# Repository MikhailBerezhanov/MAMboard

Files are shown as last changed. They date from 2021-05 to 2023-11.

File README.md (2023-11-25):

# Mobile audio module (MAM) 
## pcb

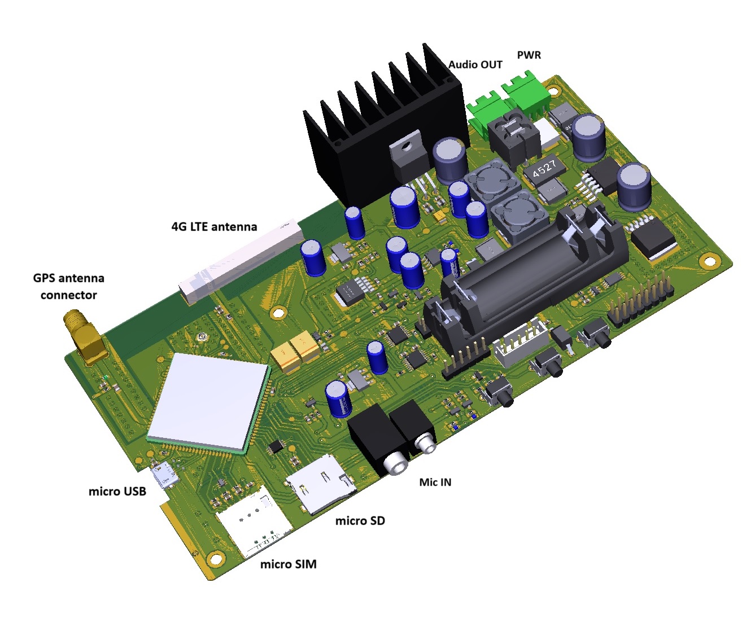
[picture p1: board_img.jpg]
board image


This project includes board scheme and manufacturing details. Current revision is `1.1`.
Board main features:
* Input power range 14V..28V
* Reserve 4.2V Accumulator power source for MPU
* Internet connection using onbard 4G LTE (SIM card needed)
* GPS connection (3V external antenna needed)
* AUDIO In (microphone input can be routed to amplified audio out)
* AUDIO Out Amplified (ready for external speaker use)
* External Memory storage (uSD card)
* ADB console (microUSB)
* Open-Linux programmable board

### Dependencies
PCB development is performed using `Altium Designer 19` or versions higher.
Components library is linked as separate submodule:

```bash
git submodule init
git submodule update
cd pcb/libs
git checkout master
```

### Manufacturing and assembly
Current project provides all necessary files for _pcb order_:

* Bill of materials (BOM)
* Gerber files
* Assembly drawings

Files mentioned above are located in:
`./pcb/vX.X/Project Outputs for Autoinformer_vX.X/`

where `X.X` is version of the board. The lastest version for now is `1.1`.

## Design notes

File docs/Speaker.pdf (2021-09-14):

### 15 ГДШ-3

Номинальное электрическое сопротивление | 4, 8 Ом
Предельная шумовая мощность | 15 Вт
Предельная кратковременная мощность | 50 Вт
Эффективный рабочий диапазон частот | 125:10000 Гц
Уровень характеристической чувствительности 89+/-4 дБ
Масса | 0.5 кг.
Габаритные размеры | 128x128x55 мм
Установочные размеры | 100x100 мм

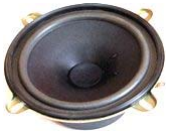
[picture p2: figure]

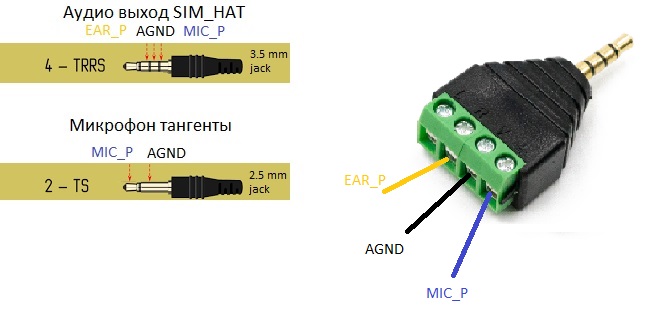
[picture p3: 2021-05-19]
docs/SIM_HAT_JACKS_PINOUT.jpg

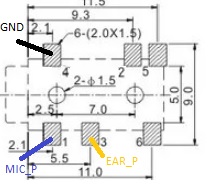
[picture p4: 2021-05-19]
docs/SIM_HAT_AUDIO_PINOUT.jpg

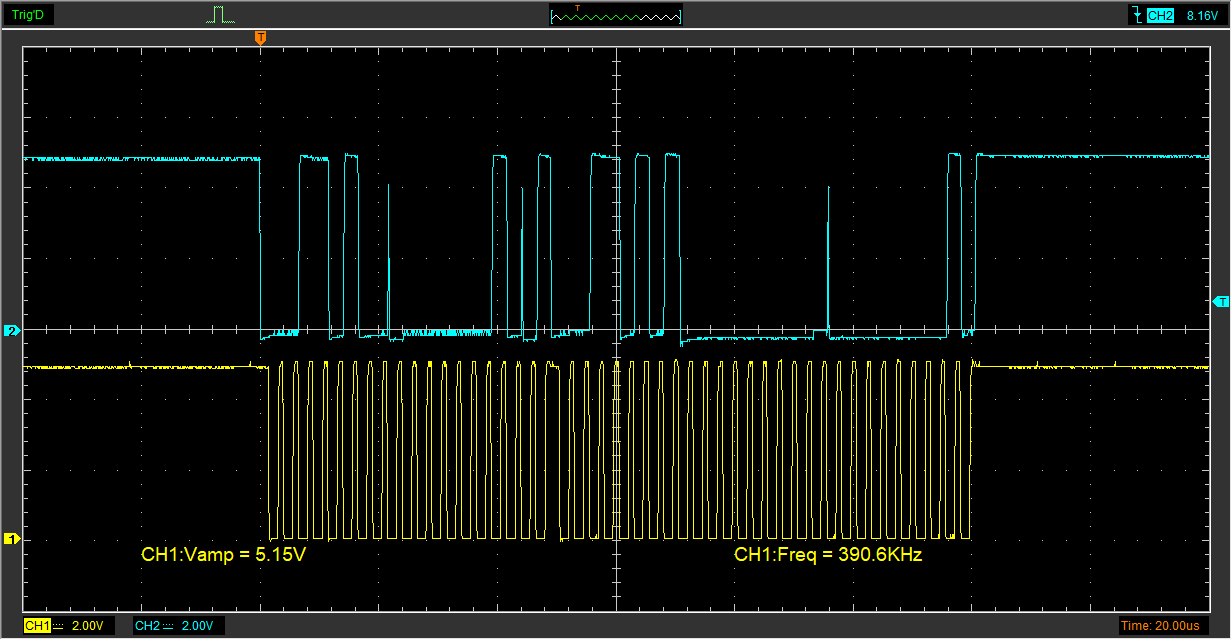
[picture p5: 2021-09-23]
docs/oscilloscopes/LCD/Real_BSS138_5V_lvl_shifter.jpg

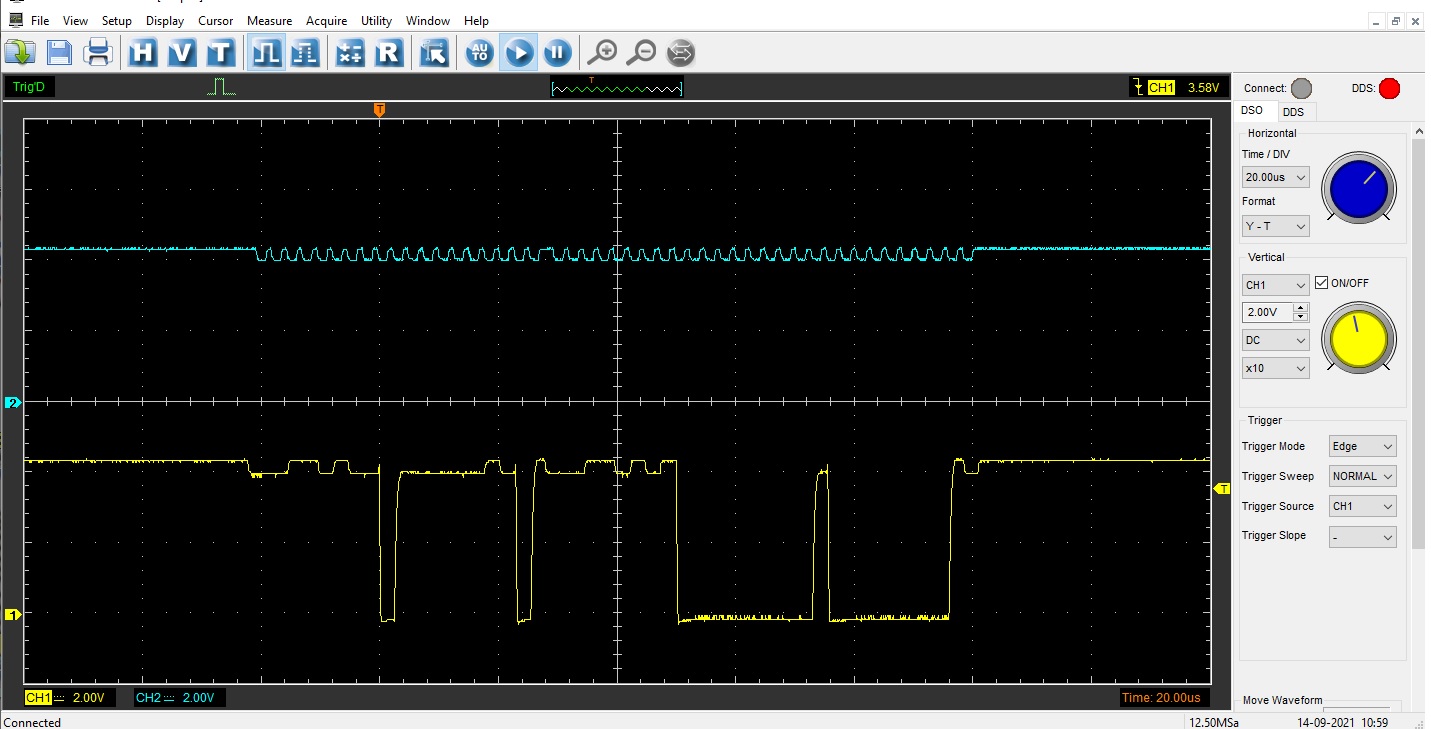
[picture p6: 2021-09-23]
docs/oscilloscopes/LCD/BSS138_lvl_shifter_i2c_400khz.jpg

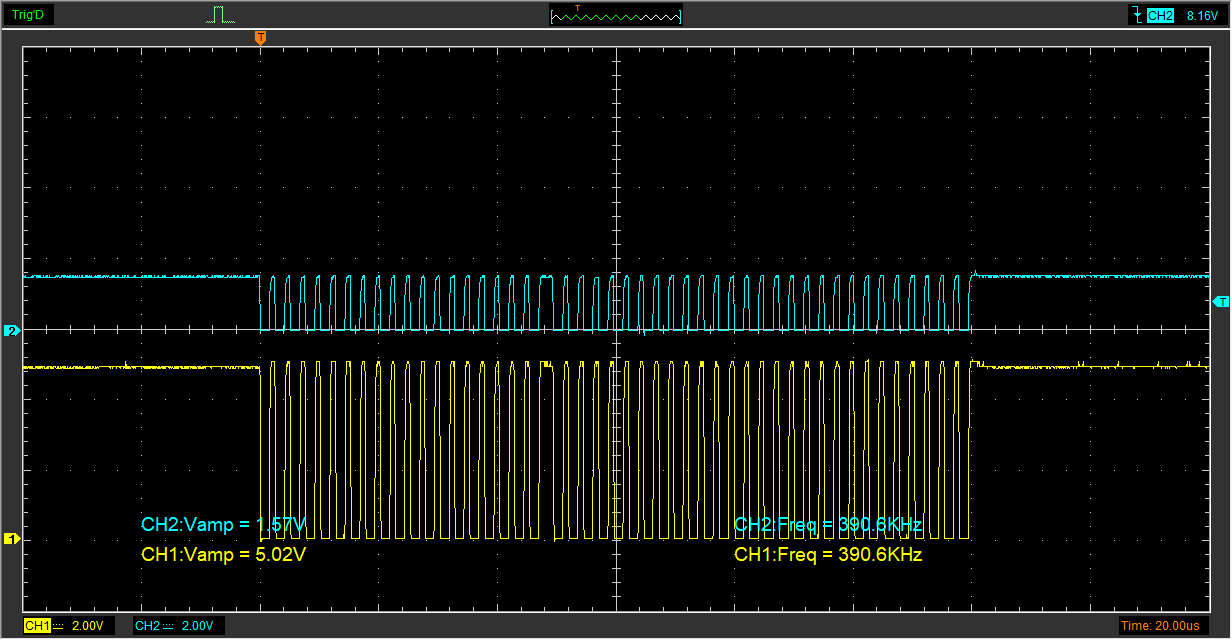
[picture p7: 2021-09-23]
docs/oscilloscopes/LCD/Real_BSS138_SCL.jpg

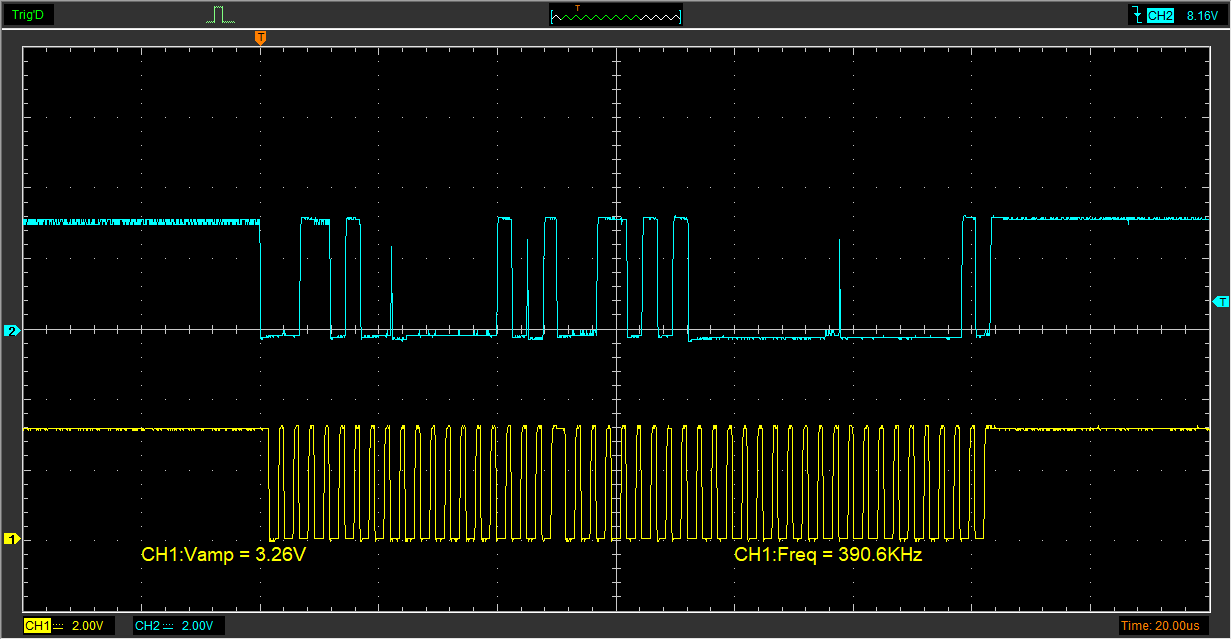
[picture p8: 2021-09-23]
docs/oscilloscopes/LCD/Real_bss318_lvll_shifter.jpg

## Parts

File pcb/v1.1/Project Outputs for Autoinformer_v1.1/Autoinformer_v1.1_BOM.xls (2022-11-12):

Designator | Comment | Description | Quantity | Link1URL | Link2URL | Link3URL | Link4URL | Link5URL | Link6URL | Link7URL
ANT1 | 146200-00011 | LTE Cellular Ceramic Antenna 698MHz-2.7GHz , SMT | 1 | https://www.elitan.ru/price/item17428368
C1, C11, C12, C13, C24, C28 | 4.7uF | GRM188R60J475KE19D | 6 | https://www.chipdip.ru/product/grm188r60j475ke19d | https://www.electronshik.ru/item/MUR/GRM188R60J475KE19D
C2, C3, C8, C14, C15, C16, C32, C34, C35, C40, C45, C46, C47, C48, C49, C52, C53, C54, C59, C67, C68, C71, C76, C77, C79, C82 | 0.1uF | GRM188R71H104KA93D | 26 | https://www.chipdip.ru/product0/226236018 | https://www.electronshik.ru/item/MUR/GRM188R71H104KA93D
C4, C6, C17, C18, C29 | 10pF | GRM1885C1H100J | 5 | https://www.chipdip.ru/product/grm1885c1h100j | https://www.electronshik.ru/item/MUR/GRM1885C1H100JA01D
C5, C7, C9, C50, C51 | 22pF | GRM1885C1H220JA01D | 5 | https://www.chipdip.ru/product/grm1885c1h220j | https://www.electronshik.ru/item/MUR/GRM1885C1H220JA01D
C10 | 10nF | GRM188R71H103K | 1 | https://www.chipdip.ru/product0/9000143994 | https://www.electronshik.ru/item/MUR/GRM188R71H103KA01D
C19, C20, C44 | 33pF | GRM1885C1H330J | 3 | https://www.chipdip.ru/product0/565764982 | https://www.electronshik.ru/item/MUR/GRM1885C1H330JA01D
C21 | 100pF | GRM1885C1H101J | 1 | https://www.chipdip.ru/product0/305749128 | https://www.electronshik.ru/item/MUR/GRM1885C1H101JA01D
C22, C23, C25, C63 | 1uF | GRM188R71E105KA12D | 4 | https://www.chipdip.ru/product/grm188r71e105ka12d | https://www.electronshik.ru/item/MUR/GRM188R71E105KA12D
C26, C27 | 470uF 6.3V | 293D477X06R3E2TE3 Конденсатор танталовый SMD тип Е | 2 | https://www.chipdip.ru/product0/145634327?from=suggest_product
C30 | 1uF | GRM31MR71E105KA01L | 1 | https://www.chipdip.ru/product/grm31mr71e105k | https://www.electronshik.ru/item/MUR/GRM31MR71E105KA01L
C31 | 10uF 10V | Конденсатор танталовый SMD 10uF 10V тип B | 1 | https://www.chipdip.ru/product0/146061461?from=suggest_product
C33, C80, C81 | 0.1uF | CL05B104KO5NNNC (CC0402KRX7R7BB104) | 3 | https://www.chipdip.ru/product1/8001849671?from=suggest_product | https://www.electronshik.ru/item/SAMSUNG/CL05B104KO5NNNC
C36 | 0.039uF | CC0603KRX7R9BB393 | 1 | https://www.chipdip.ru/product0/8160066189?from=suggest_product | https://www.elitan.ru/price/item8778633 | https://www.electronshik.ru/item/YAG/CC0603KRX7R9BB393
C37 | K50-35 470uF 16V | Конденсатор электролитический алюминиевый 470мкФ, 16В, 8х12мм Р:3.5мм | 1 | https://www.chipdip.ru/product0/9000565914
C38, C39 | K50-35 1000uF 25V | Конденсатор электролитический алюминиевый 1000мкФ, 25В, 10x21мм | 2 | https://www.chipdip.ru/product0/9000565765?from=suggest_product
C41 | 22pF | GRM21A5C2E220J (CC0805JRNPO9BN220) | 1 | https://www.chipdip.ru/product0/29844 | https://www.electronshik.ru/item/MUR/GRM21A5C2E220JW01D
C42, C43 | NС | 0603 SMD Capacitor | 2
C55 | 100pF 2kV | C1206C101KGRACAUTO (CC1206JKNPODBN101) | 1 | https://www.elitan.ru/price/item16896874 | https://www.electronshik.ru/item/KEM/C1206C101KGRACAUTO
C56 | K50-35 220uF 50V | SH050M0220B5S-1012 ECAP 10*12 Конденсатор электролитический алюминиевый | 1 | https://www.chipdip.ru/product0/9000565903
C57, C64 | 10uF | GRM188R61E106M | 2 | https://www.chipdip.ru/product/grm188r61e106m | https://www.electronshik.ru/item/MUR/GRM188R61E106MA73D
C58 | K50-35 220uF 16V | ECA1CM221 6.3x11 P:2,5мм Конденсатор электролитический алюминиевый | 1 | https://www.chipdip.ru/product0/9000565899
C60, C69, C74, C75 | K50-35 220uF 6.3V | ECA0JHG221 5x11мм Р:2,5мм Конденсатор электролитический алюминиевый | 4 | https://www.chipdip.ru/product0/9000261774?from=suggest_product
C61 |  | НЕ УСТАНАВЛИВАТЬ
C62 | K50-35 100uF 16V | SH016M0100A2F-0511 5x11мм Конденсатор электролитический алюминиевый | 1 | https://www.chipdip.ru/product0/9000565888
C65, C78 | K50-35 33uF 6.3V | Конденсатор электролитический алюминиевый 33 мкФ, 6.3 В, 4х7мм | 2 | https://www.chipdip.ru/product0/9000261769
C66 | 0.47uF | C1608X7R1H474K080AC (CC0603KRX7R9BB474) | 1 | https://www.chipdip.ru/product0/8576565346 | https://www.electronshik.ru/item/TDK/C1608X7R1H474K080AC
C70 | K50-35 680uF 25V | Конденсатор электролитический алюминиевый 680мкФ, 25В, 10х16мм Р:5мм | 1 | https://www.chipdip.ru/product0/9000565919
C72, C73 | K50-35 100uF 10V | SH010M0100B2F-0511 5x11мм Конденсатор электролитический алюминиевый | 2 | https://www.chipdip.ru/product0/46079?from=suggest_product | https://www.chipdip.ru/product0/9000565886
D1 | SIM7600E-H | Multi-Band LTE-TDD/LTE-FDD/HSPA+ and GSM/GPRS/EDGE module | 1 | http://www.mt-system.ru/SIMCom/SIM7600E-H
D2 | NAU8810YG | AUDIO CODEC MONO 20QFN | 1 | https://upverter.com/upn/revision/eec1ccdac07fe113/ | http://www.nuvoton.com/hq/resource-download.jsp?tp_GUID=DA00-NAU8810.1 | https://www.elitan.ru/price/index.php?find=NAU8810YG&delay=-1&mfg=all&seenform=y
D3 | TXB0102DCU | Voltage Level Translator Bidirectional 1 Circuit 2 Channel 100Mbps 8-VSSOP | 1 | https://www.elitan.ru/price/item692394 | https://www.chipdip.ru/product0/8002872138?from=suggest_product | https://www.electronshik.ru/item/TI/TXB0102DCUR
D4 | TXB0104PWR | 4-Bit Bidirectional Voltage-Level Shifter with Auto Direction Sensing and +/-15 kV ESD Protect 14-TSSOP -40 to 85 | 1 | https://www.elitan.ru/price/item703962
D5 |  | НЕ УСТАНАВЛИВАТЬ
D6 | MCP130T-450I/TT | 4.50 V 150 ms Microcontroller Supervisory Circuit - SOT-23-3 | 1 | https://www.elitan.ru/price/item505438 | https://www.electronshik.ru/item/MCRCH/MCP130T-450I%3A%3ATT
D7 | NB3N501DG | PLL Clock Multiplier Single 8-Pin SOIC 3 V ~ 5.25 V | 1 | https://www.elitan.ru/price/item9787428 | https://www.electronshik.ru/item/ONS/NB3N501DG
D8 | PCF8574AT | 8-bit I/O expander for I2C bus with interrupt PCF8574(A)T/3 - 100kHz version PCA8574(A)D - 400kHz version | 1 | https://www.elitan.ru/price/item981552 | https://www.electronshik.ru/item/NXP/PCF8574AT%3A%3A3.518
DA1 | TDA2003V | Amplifier IC 1-Channel _Mono_ Class AB 5-PENTAWATT 10W | 1 | https://www.elitan.ru/price/item123031 | https://www.chipdip.ru/product/tda2003v?from=suggest_product | https://www.chipdip.ru/product/hs-117-30
DA2 | LM2576S-5.0 | Импульсный понижающий регулятор напряжения, 5В, 3А, [TO-263] | 1 | https://www.chipdip.ru/product/lm2576sx-5.0-nopb | https://www.elitan.ru/price/item100181
DA3 | TP4056 | Li-lon Battery Charger 1A Standalone Linear with Thermal Regulation in SOP-8 | 1 | https://www.elitan.ru/price/item26170288 | https://www.electronshik.ru/item/YOUTAI/TP4056
DA4 | LM2577S-ADJ | Преобразователь постоянного тока повышающий 3 А вход 3.5...40В выход 5...60В -40...+125°С | 1 | https://www.elitan.ru/price/item100192 | https://www.electronshik.ru/item/TI/LM2577S-ADJ%3A%3ANOPB
DA5 | MIC29302WU | 3A Fast Response LDO Regulator Operating Input Voltage Range: 3V to 16V 1.24V to 15V Adjustable Output Voltage | 1 | https://www.elitan.ru/price/item637427 | https://www.chipdip.ru/product0/8000649332 | https://www.electronshik.ru/item/MCRCH/MIC29302WU
DA6 | LM1117GS-ADJ | LDO +1.25...13.8 В, 1А [SOT-223] Линейный регулятор с низким падением напряжения, Максимальное входное напряжение, 20 В | 1 | https://www.chipdip.ru/product/lm1117gs-adj | https://www.elitan.ru/price/item21580115
DA7 | LM1117GS-3.3 | LDO +3.3 В, 1А [SOT-223] Линейный регулятор с низким падением напряжения, Максимальное входное напряжение, 20 В | 1 | https://www.chipdip.ru/product/lm1117gs-3.3 | https://www.elitan.ru/price/item21580113
DD1 | STM32L151CBT6A | Analog - STM32L071C8T6 Микроконтроллер 32-Бит, Cortex-M3, 32МГц, 128КБ Flash, LCD, USB, ADC, DAC [LQFP-48] | 1 | https://www.elitan.ru/price/item11268663 | https://www.chipdip.ru/product/stm32l151cbt6a-2
F1 | MF-SM185/33-2 | Самовосстанавливающийся предохранитель PTC 1.8A(hold) 3.6A(trip) 33VDC 40A 1.9W 5s 0.04Ohm SMD 3425 Solder Pad 9.5 X 6.71 X 3mm | 1 | https://www.elitan.ru/price/item781521 | https://www.chipdip.ru/product0/8001787493?from=suggest_product
F2 | 1812L125/6PR | Предохранитель SMD 6 VDC 2.5 A | 1 | https://www.elitan.ru/price/item387111 | https://www.electronshik.ru/item/LTL/1812L125%3A%3A6PR
HL1 | TO-1608BC-MYF | Vf =2 V, 20mA, 0603 (HL-PST-1608S31YC) | 1 | https://www.chipdip.ru/product/to-1608bc-myf?from=suggest_product | https://www.chipdip.ru/product/gnl-3012ed
HL2 | TO-1608BC-MRE | Vf =2 V, 20mA, 0603 (HL-PST-1608S9AC) | 1 | https://www.chipdip.ru/product/to-1608bc-mre?from=suggest_product | https://www.elitan.ru/price/item16986056 | https://www.chipdip.ru/product/gnl-3012ed
HL3 | TO-1608BC-PG | Vf =3.3 V, 20mA, 0603 (HL-PST-1608U51GC) | 1 | https://www.chipdip.ru/product/to-1608bc-pg?from=suggest_product | https://www.elitan.ru/price/item16986058
HL4 | TO-1608BC-BF | Vf =3.3 V, 20mA, 0603 (HL-PST-1608H203BC) | 1 | https://www.chipdip.ru/product/to-1608bc-bf?from=suggest_product | https://www.elitan.ru/price/item16986057
IND1 | BLM21PG121SN1D | 0805, Дроссель подавления ЭМП 120Ohm 25% 100MHz 3A | 1 | https://www.chipdip.ru/product0/8228217893 | https://www.elitan.ru/price/item1364359
IND2, IND3, IND4, IND8, IND9 | BLM21SP102SN1D | 0805, Дроссель подавления ЭМП 1KOhm 25% 100MHz 1.6A 0.12Ohm | 5 | https://www.chipdip.ru/product/blm21sp102sn1d | https://www.elitan.ru/price/item21298136
IND5, IND7 | BLM21PG221SN1D | 0805, Дроссель подавления ЭМП 220Ohm +25% 100MHz 2A 45mOhm | 2 | https://www.chipdip.ru/product/blm21pg221sn1d | https://www.elitan.ru/price/item305175
IND6 | BLM21PG300SN1D | 0805, Дроссель подавления ЭМП 100МГц:30Ом; 3А | 1 | https://www.chipdip.ru/product/blm21pg300sn1d | https://www.elitan.ru/price/item310735
L1 | LQG18HN47NJ | Чип индуктивность многослойная неэкранированная 47нГн 5% 100МГц Maximum DC Current 300 mA Maximum DC Resistance 700 mOhms | 1 | https://www.elitan.ru/price/item307313 | https://www.chipdip.ru/product/lqg18hn47nj?from=suggest_product
L2 | SRR1208-330YL | SMD индуктивность проволочная, на ферритовом сердечнике, экранированная 33uH 15% 1KHz 23Q-Factor Ferrite 2.8A 62mOhm | 1 | https://www.chipdip.ru/product/srr1208-330yl?from=suggest_product | https://www.elitan.ru/price/item319349
L3 | SRR1208-680YL | SMD индуктивность проволочная, на ферритовом сердечнике, экранированная 68uH 15% 1KHz 23Q-Factor Ferrite 2.8A 62mOhm | 1 | https://www.chipdip.ru/product1/8002012849?from=suggest_product | https://www.elitan.ru/price/item782382
LC1 | BNX003-01 | EMI фильтр индуктивно-емкостной 10A 150VDC 40дБ | 1 | https://www.elitan.ru/price/item279156 | https://www.chipdip.ru/product/bnx003-01?from=suggest_product
R1, R2, R9, R11, R13, R78 | 0 | RC0603JR-070RL | 6 | https://www.chipdip.ru/product0/9000070541 | https://www.electronshik.ru/item/YAG/RC0603JR-070RL
R3, R73 | 68 | RC0603FR-0768RL | 2 | https://www.chipdip.ru/product0/9000079612 | https://www.electronshik.ru/item/YAG/RC0603FR-0768RL
R4, R5, R6, R27, R28, R31, R34, R35, R36, R38, R46, R47, R48, R49, R74, R75, R79, R80, R81, R82 | 10k | RC0603FR-0710KL (CRCW060310K0FKEA) | 20 | https://www.chipdip.ru/product0/9000079736 | https://www.electronshik.ru/item/VISHAY/CRCW060310K0FKEA
R7, R8, R10, R12, R32 |  | НЕ УСТАНАВЛИВАТЬ
R14, R15, R16 | 22 | RC0603FR-0722RL (RC0603JR-0722RL) | 3 | https://www.chipdip.ru/product0/9000079564 | https://www.electronshik.ru/item/FENGHUA/0603%20-22%20%D0%9E%D0%BC%205%25%20RC0603JR-0722RL%20%5BRS-03K220JT%5D
R17, R20, R21, R26, R29, R39 | 2.2k | RC0603FR-072K2L | 6 | https://www.chipdip.ru/product0/9000079720 | https://www.electronshik.ru/item/YAG/RC0603FR-072K2L
R18, R19, R64, R67 | 1k | RC0603FR-071KL | 4 | https://www.chipdip.ru/product0/9000079676 | https://www.electronshik.ru/item/YAG/RC0603FR-071KL
R22, R23, R24 |  | НЕ УСТАНАВЛИВАТЬ
R25 |  | НЕ УСТАНАВЛИВАТЬ
R30, R40 | 360 | RC0603FR-07360RL | 2 | https://www.chipdip.ru/product0/9000079629 | https://www.electronshik.ru/item/YAG/RC0603FR-07360RL
R33 | 22k | RC0603FR-0722KL | 1 | https://www.chipdip.ru/product0/9000079744 | https://www.electronshik.ru/item/YAG/RC0603FR-0722KL
R37 | 39 | RC0603FR-0739RL | 1 | https://www.chipdip.ru/product0/9000079606 | https://www.electronshik.ru/item/YAG/RC0603FR-0739RL
R41 | 43 | RC0603FR-0743RL | 1 | https://www.chipdip.ru/product0/9000079607 | https://www.electronshik.ru/item/YAG/RC0603FR-0743RL
R42 | 2.2 | RC0603FR-072R2L | 1 | https://www.chipdip.ru/product0/9000079549 | https://www.electronshik.ru/item/YAG/RC0603FR-072R2L
R43 | 1 | RC0603FR-071RL | 1 | https://www.chipdip.ru/product0/9000079509 | https://www.electronshik.ru/item/YAG/RC0603FR-071RL
R44, R68 | 0 | RC0805JR-070RL | 2 | https://www.chipdip.ru/product0/153356071 | https://www.electronshik.ru/item/YAG/RC0805JR-070RL
R45 | 10 | RC0603FR-0710RL | 1 | https://www.chipdip.ru/product0/9000079557 | https://www.electronshik.ru/item/YAG/RC0603FR-0710RL
R50 | 1M | RC1206JR-071ML | 1 | https://www.chipdip.ru/product0/690816980 | https://www.electronshik.ru/item/YAG/RC1206JR-071ML
R51 | 18k | RC0603FR-0718KL | 1 | https://www.chipdip.ru/product0/9000079742 | https://www.electronshik.ru/item/YAG/RC0603FR-0718KL
R52 | 3.9k | RC0603FR-073K9L | 1 | https://www.chipdip.ru/product0/9000079726?from=suggest_product | https://www.electronshik.ru/item/YAG/RC0603FR-073K9L
R53 | 2 | WSC45272R000FEA SMD чип резистор, с проволочной обмоткой, 4527, 2 Ом, Серия WSC, 2 Вт | 1 | https://www.chipdip.ru/product/wsc45272r000fea?from=suggest_product | https://www.elitan.ru/price/item572273
R54 | 1.2k | RC0603FR-071K2L | 1 | https://www.chipdip.ru/product0/9000079678 | https://www.electronshik.ru/item/YAG/RC0603FR-071K2L
R55 |  | НЕ УСТАНАВЛИВАТЬ
R56 |  | НЕ УСТАНАВЛИВАТЬ
R57 | 16k | RC0603FR-0716KL | 1 | https://www.chipdip.ru/product0/9000079741 | https://www.electronshik.ru/item/YAG/RC0603FR-0716KL
R58 | 1.5k | RC0603FR-071K5L | 1 | https://www.chipdip.ru/product0/9000079716?from=suggest_product | https://www.electronshik.ru/item/YAG/RC0603FR-071K5L
R59, R63 | 100k | RC0603FR-07100KL | 2 | https://www.chipdip.ru/product0/9000079760 | https://www.electronshik.ru/item/YAG/RC0603FR-07100KL
R60 | 47k | RC0603FR-0747KL | 1 | https://www.chipdip.ru/product0/9000079752 | https://www.electronshik.ru/item/YAG/RC0603FR-0747KL
R61 | 470 | RC0805FR-07470RL | 1 | https://www.chipdip.ru/product0/9000079478 | https://www.electronshik.ru/item/YAG/RC0805FR-07470RL
R62 | 10k (NC) | RC0603FR-0710KL (CRCW060310K0FKEA) | 1 | https://www.electronshik.ru/item/VISHAY/CRCW060310K0FKEA | https://www.chipdip.ru/product0/9000079736
R65 | 1.3k | RC0603FR-071K3L | 1 | https://www.chipdip.ru/product0/9000079679 | https://www.electronshik.ru/item/YAG/RC0603FR-071K3L
R66 | 0.1 | RL0805FR-070R1L | 1 | https://www.elitan.ru/price/item503786 | https://www.electronshik.ru/item/YAG/RL0805FR-070R1L
R69 | 3.3k | RC0603FR-073K3L | 1 | https://www.chipdip.ru/product0/9000079724 | https://www.electronshik.ru/item/YAG/RC0603FR-073K3L
R70 | 7.5k | RC0603FR-077K5L | 1 | https://www.chipdip.ru/product0/9000079733 | https://www.electronshik.ru/item/YAG/RC0603FR-077K5L
R71 | 1k | RC0402FR-071KL | 1 | https://www.chipdip.ru/product0/9000189652?from=suggest_product | https://www.electronshik.ru/item/YAG/RC0402FR-071KL
R72 | 1k | RC1206FR-071KL | 1 | https://www.chipdip.ru/product0/9000079635 | https://www.electronshik.ru/item/YAG/RC1206FR-071KL
R76, R84 | 2k | RC0603FR-072KL | 2 | https://www.chipdip.ru/product0/9000079719 | https://www.electronshik.ru/item/YAG/RC0603FR-072KL
R77 |  | НЕ УСТАНАВЛИВАТЬ
R83 | 5.6k | RC0603FR-075K6L | 1 | https://www.chipdip.ru/product1/8001784532 | https://www.electronshik.ru/item/YAG/RC0603FR-075K6L
S1, S2, S3, S5 | KLS7-TS6606 | 6x6 Tact Switch Series | 4 | https://www.chipdip.ru/product/kls7-ts6606-7.0-180-tc-0206 | https://www.elitan.ru/price/item22675038
S4 | 1437566-3 | SMD button | 1 | https://www.chipdip.ru/product/tyco-1437566-3-fsmsm?from=suggest_product | https://www.elitan.ru/price/item565583
VD1 | SMF05C | 12.5V Clamp 8A _8/20µs_ Ipp Tvs Diode Surface Mount SC-88/SC70-6/SOT-363 | 1 | https://www.elitan.ru/price/item10155001 | https://www.chipdip.ru/product/smf05ct1g?from=suggest_product
VD2, VD3, VD4 | ESD9L5.0ST5G | TVS диод защитный 5В_пиковое_рабочее 9.8В_ограничение SOD923 | 3 | https://www.elitan.ru/price/index.php?find=ESD9L5.0ST5G&delay=-1&mfg=all&seenform=y | https://www.chipdip.ru/product0/8001926257
VD5, VD18 | ESDA6V1SC5 | Сборка защитная TVS-диодов 5.25В_пиковое_ SOT23-5 Unidirectional Channels 4 Voltage - Reverse Standoff (Typ) 5.25V Voltage - Breakdown (Min) 6.1V | 2 | https://www.elitan.ru/price/item317230 | https://www.electronshik.ru/item/ST/ESDA6V1SC5 | https://www.chipdip.ru/product0/8001797118?from=suggest_product
VD6 | SP0503BAHTG | TVS Diode-3 Рабочее напряжение 5.5 В Максимальное напряжение фиксации 8.5 в | 1 | https://www.chipdip.ru/product/sp0503bahtg | https://www.elitan.ru/price/item393293
VD7 | MMSZ5231B-TP | Стабилитрон 5.1В, 5%, 0.5Вт, [SOD-123] | 1 | https://www.chipdip.ru/product/mmsz5231b-tp?from=suggest_product | https://www.elitan.ru/price/item685173
VD8, VD9, VD17 | ESD9L3.3ST5G | TVS диод защитный 5В_пиковое_рабочее 9.8В_ограничение SOD923 | 3 | https://www.elitan.ru/price/item1205491 | https://www.chipdip.ru/product1/8002974897?from=suggest_product
VD10 | LXES15AAA1-153 | TVS диоды Подавители ЭСР / диоды для подавления переходных скачков напряжения ESD Protection Device | 1 | https://www.chipdip.ru/product0/8001818635?from=suggest_product | https://www.elitan.ru/price/item11962267
VD11, VD16 | SS36 | Schottky; DO-214AB; 3.0A IF; 0.75V; 60V; 100A IFRM; 10000V/us; 1000pF | 2 | https://www.elitan.ru/price/item499214 | https://www.chipdip.ru/product/ss36-e3-57t-2?from=suggest_product
VD12 | SS510 | Диод Шоттки 5A 100V (SMC) | 1 | https://www.chipdip.ru/product0/8002382677?from=suggest_product | https://www.elitan.ru/price/item24826922
VD13 | SM15T39CA | TVS Diode Bi-Directional SM15T39CA 69.7V, 1500W, SMC 2-Pin | 1 | https://www.chipdip.ru/product/sm15t39ca?from=suggest_product | https://www.elitan.ru/price/item636974
VD14 | BAT60AE6327HTSA1 | Диод Шоттки 3А 10В [SOD-323] | 1 | https://www.chipdip.ru/product/bat60a?from=suggest_product | https://www.elitan.ru/price/item9533309
VD15 | SS34 | Schottky; DO-214AB; 3.0A IF; 0.75V; 40V; 100A IFRM; 10000V/us; 1000pF | 1 | https://www.chipdip.ru/product/ss34-5 | https://www.elitan.ru/price/item9505516
VT1 | 2N7002 | N-Channel MOSFET 60В 0.115А [SOT-23] | 1 | https://www.chipdip.ru/product/2n7002-tp-reel-3000 | https://www.elitan.ru/price/item484309
VT2, VT3 | BC850B | Transistor, Npn, 0.1A, 50V, Vbe = 0.7V, hfe = 240 [ SOT23 ] | 2 | https://www.chipdip.ru/product/bc850b?from=suggest_product | https://www.elitan.ru/price/item5642305
VT4 |  | НЕ УСТАНАВЛИВАТЬ
VT5 | BSS138 | MOSFET, N-канал, 0.2А, 50В, [SOT-23] | 1 | https://www.chipdip.ru/product/bss138-7-f-diodes?from=suggest_product | https://www.elitan.ru/price/item305174
VT6, VT7 | IRLML6402 | P-Channel 20V 3.7A _Ta_ 1.3W _Ta_ Surface Mount/SOT-23 | 2 | https://www.chipdip.ru/product/irlml6402tr?from=suggest_product | https://www.elitan.ru/price/item13518502
VT8, VT9, VT10 | BSS138 | MOSFET, N-канал, 0.2А, 50В, [SOT-23] | 3 | https://www.chipdip.ru/product/bss138-7-f-diodes?from=suggest_product | https://www.elitan.ru/price/item305174
VT11 | SI2308BDS-T1-GE3 | MOSFET, N-канал 60В 1.9А [SOT-23] | 1 | https://www.chipdip.ru/product/si2308bds-t1-ge3-vishay | https://www.electronshik.ru/item/VISHAY/SI2308BDS-T1-GE3 | https://www.elitan.ru/price/item668096
X1 | 5039600696 | Соединители для карт памяти 1mm microSIM Push Push SMT | 1 | https://www.elitan.ru/price/item12310026
X2 | 112J-TDAR-R | Разъем: для карт памяти; SD Micro; push-push; SMT; позолота | 1 | https://www.chipdip.ru/product0/8002703228 | https://www.elitan.ru/price/item10898530
X3 | 1050170001 | USB - micro B USB 2.0 Receptacle Connector 5 Position Surface Mount, Right Angle; Through Hole | 1 | https://www.elitan.ru/price/item5116026 | https://www.chipdip.ru/product/105017-0001-molex?position_type={position_type}|k50id|pla-293946777986|cid|11945324864|aid|488785225626|gid|115765259517&utm_campaign=G_tovarnieobjavlenija&utm_content=text1_ga&utm_term=
X4 | PY-401N | Гнездо моно 2.5мм | 1 | https://www.elitan.ru/price/index.php?find=PY-401N&delay=-1&mfg=all&seenform=y | https://www.chipdip.ru/product/py-401n
X5 | PY-601N | Аудио гнездо (М) 3.5мм | 1 | https://www.chipdip.ru/product/py-601n?from=suggest_product | https://www.elitan.ru/price/index.php?find=PY-601N&delay=-1&mfg=all&seenform=y
X6, X13 | DS1021_1x2 | Вилка штыревая 2.54мм 1x2 прямая PLS-2 | 2 | https://www.chipdip.ru/product/pls-2 | https://www.elitan.ru/price/item10669650
X7 | DS1013-14M | Вилка на плату прямая 14 конт. 2.54мм ответная часть: DS1016-14MA2BB или IDC-14F шлейф DS1057-14A282R-30.5 | 1 | https://www.elitan.ru/price/item21920938 | https://www.electronshik.ru/item/CONNFLY/DS1013-14MSIXA-B | https://www.chipdip.ru/product0/8160149550
X8, X15 | 2EDGR-5.08-02P | Клеммник разъемный угловой 2 конт., шаг 5.08 мм (KLS2-EDR-5.08-02P-4) 2EDGK-5.08-02P - ответная часть | 2 | https://www.chipdip.ru/product/kls2-edr-5.08-02p-4-2edgr-5.08-02p | https://www.elitan.ru/price/item21239767
X9 | U_FL-R-SMT-1_10 | Разъем РЧ / 50 Ом Коаксиальный, UFL Коаксиальный, Прямое Гнездо, Вертикальный Поверхностный Монтаж SMT | 1 | https://www.elitan.ru/price/item1203541 | https://www.chipdip.ru/product0/9000586248?from=suggest_product
X10 | KLS1-SMA002-B | Разъем угловой SMA гнездо на плату 50 Ом | 1 | https://www.platan.ru/cgi-bin/qwery.pl/id=356964102 | https://www.elitan.ru/price/item9893558
X11 | DS1021-2*3SF11-B | Вилка штыревая 2.54мм 2x3 прямая тип1 | 1 | https://www.chipdip.ru/product/pld-6 | https://www.electronshik.ru/item/CONNFLY/DS1021-2x3SF11-B
X12 | DS1021_2x8 | Вилка штыревая 2.54мм 2х8 прямая PLD-16 | 1 | https://www.chipdip.ru/product/pld-16 | https://www.elitan.ru/price/item14835380
X14 | Keystone 1029 | 16340 2/3A Battery Holder | 1 | https://www.elitan.ru/price/item468733
Y1 | HC49SM-8MHz | 8 MHz resonator | 1 | https://www.chipdip.ru/product/8mhz-hc-49sm | https://www.elitan.ru/price/item2093968
Закрепить к DA1 | HS 117-30 | Радиатор 30х43х20 мм, 7.1 дюйм*градус/Вт | 1 | https://magzaryada.ru/akkumulyatory/14500-16340/eagletac-16340-rcr123 | https://www.lacrosse-nn.ru/%D0%B0%D0%BA%D0%BA%D1%83%D0%BC%D1%83%D0%BB%D1%8F%D1%82%D0%BE%D1%80%D1%8B-li-ion-14500-16340-rcr123/eagtac-16340-750mah-4-5a/
 | Винт М2х6 круг , пл | Крепеж радиатора к плате | 2 | https://www.chipdip.ru/product/hs-117-30 | https://www.electronshik.ru/item/KLS/HS117-30
 | GD900 30g | Термопаста | 1 | https://www.electronshik.ru/item/WINSTAR/WH1602B-YYK-CTK%23
 | Винт М3 | Крепеж радиатора к микросхеме | 1 | https://mirekom.ru/price/product-11016.15 | https://www.sovelektron.com/vint-pf2-6/
 |  |  |  | https://mirekom.ru/price/product-6612.20 | https://www.elitan.ru/price/item130957 | https://www.chipdip.ru/product/kls2-edk-5.08-02p-4s-2esdv-02p?from=suggest_product
 |  |  |  | https://www.elitan.ru/price/item8570145 | https://www.electronshik.ru/item/CONNFLY/DS1016-14MA2BB
 |  |  |  | https://www.electronshik.ru/item/CONNFLY/DS1057-14A282R-30.5 | https://www.chipdip.ru/product/ds1057-14-30
 |  |  |  | https://tgt-store.ru/272186/ | https://aliexpress.ru/item/33047821777.html

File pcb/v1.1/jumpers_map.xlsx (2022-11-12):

Позиционное обозначение | Назначение | Конфликтует с | Примечание
R78 | Соединяет 12 МГц с MCLK (NAU8810) | R25
R25 | Соединяет PCM_CLK с MCLK (NAU8810) | R78 | NC
R71 | Задает коэф. Умножителя частоты D7 | D7 ICS512M | NC если в качестве D7 используется ICS512M
R2 | Подключение сигнала микрофона к AGND при отсутствии штекера
R1 | Pull-up кнопок к 1.8V (MPU) | R7
R7 | Pull-up кнопок к 3.3V (MCU) - не используется | R1 | NC
R8 | Подключение кнопки S1 к MCU | R9 | NC
R9 | Подключение кнопки S1 к MPU | R8
R10 | Подключение кнопки S2 к MCU | R11 | NC
R11 | Подключение кнопки S2 к MPU | R10
R12 | Подключение кнопки S3 к MCU | R13 | NC
R13 | Подключение кнопки S3 к MPU | R12
R32 | Автовключение SIMCOM (PWRKEY к GND) |  | NC
R22 | Подключение MAIN_ANT_GND к GND |  | NC
R23 | Подключение AUX_ANT_GND к GND |  | NC
R24 | Подключение GNSS_ANT_GND к GND |  | NC
R68 | Подключение "-" аккумулятора к GND в отсутстсвие VT4 | VT4, DA3
R77 | Дополнительная нагрузка для STEP-UP DC-DC (LM2577) | TDA2003V | NC

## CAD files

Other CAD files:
docs/3d_models/HS117-30.ipt
docs/3d_models/PY-401N.ipt
docs/3d_models/PY-601N.ipt

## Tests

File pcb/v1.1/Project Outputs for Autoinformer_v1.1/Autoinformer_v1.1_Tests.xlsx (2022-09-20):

Проверяемая часть | Результат | Подробности | Доработки
MPU SIMCOM | OK
SD | OK
SIM | OK
USB | OK
LTE/4G | OK | В ОС интерфейс появился не сразу. Возможно это связано с регистрацией симки \ модуля в сотовой сети. RSSI : -69 dB (дома) , -57 dB (в офисе). Отличные показатели: RSSI до -65 Хорошие показатели: RSSI от -65 до -75
GPS/GNSS | OK
LEDs GPIO | OK
Buttons GPIO | NORM | У кнопок S1..S3 оказалась другая распиновка | Переделать посадочное место KLS7-TS6606 -7.0
ADC1 | NORM | Питание микрофона MICBIAS выдается не аппаратно (не постоянно), а программно (включается и отключается) из-за чего показания АЦП оказываются не всегда корректны
I2C NAU8810 | OK
AUDIO OUT | NORM | Наводки на аудиоусилитель от антенны при сотовой связи вызывают слышимые пощелкивания динамика
Тангента | NORM | При нажатии кнопки (включении микрофона) динамик начинает громко свистеть из-за возникающей обратной связи микрофона с усилителем. | Между MOUT и С31 поставить регулятор громкости (переменный резистор 10к - 47к)
MCU STM32 | OK | GPIO_79 не доступен в ОС
UART | OK | R46, R47 не напаивать
I2C LCD | FAIL | 1. Экран немного моргает. У i2c преобразователя диспеля необходимо отпаять подтягивающие SDA и SCL резисторы 4.7k т.к. они уже есть на плате 2. Микросхема управления дисплеем не может ответить на команды. Выбран преобразователь уровней не поддерживающий open-drain порты | 1. Добавить конденсатор и дроссель от ЭМП по питанию. 2. Заменить D3 на TXS0104EPW
Внешнее питание | OK
MAX Потребление | OK | Условия испытаний: Обмен по 4G, Включен GPS, Заряжается аккумулятор, Воспроизводится Аудио. 12 V - 1.2 A, 24 V - 0.6 A
Защита по питанию |  | кротковременное КЗ на входе - ОК Запуск от аккума - ОК На входе 7 В \ 30 В - ОК
Аккумуляторное питание | NORM | 1. При остутствии внешнего питания образующийся делитель R64 | (R33 + R34) нарушает работу инвертора VT5, в результате через VT6 (открыт) напряжение аккумулятора оказывается на 3V8_EXT, ломая логику схемы. 2. При переходе с внешнего питания на резервное напряжение аккумулятора с VT7(D) оказывается на открытом VT6 (RST не успевает сброситься и через VT5 закрыть VT6), что приводит снова к попаданию 3V8_INT на 3V8_EXT, нарушая логику схемы. 3. Если в момент зарядки аккумулятора (DA3 синий светодиод горит) происходит отключени основого питания, видимо через микросхему напряжение с батареи попадает на линию 5 V, нарушая правила питания платы. | 1. Изменить номиналы R64 1k, R33 22k, R34 15k или поставить ключ (или взять сигнал на делитель до инвертора (пин 1 MCP130). R63 будет избыточен. Вместо него будут R33, 34) 2. Запитывать D6 не 3V8_EXT, а 5V . 3. Поменять пороговое напряжение сброса D6 (поставить MCP130T-450I/TT) чтобы VT6 закрывался и не давал устанавливаться 3V8_EXT -> 5V.
Переход на аккум. питание BAK_ON GPIO | NORM | ОС не дает обратиться к GPIO_1020 т.к. его использует один из драйверов | Перенести сигнал на ADC2 (?) или использовать встроенный в модуль монитор напряжения питания через АТ-команду
Заряд аккумулятора | OK | Зарядка до 4.2 В макс ток 1 А
Заключение: |  | Плата пригодна для демонстрации функционала и разработки ПО, но для выхода в свет требуются доработки

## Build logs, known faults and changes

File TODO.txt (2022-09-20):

--- Версия 1.0 ---

+ 1. Уточнить номиналы делителя 1.8В для ADC1 (входное R = 1 МОм) 
+ 2. Заменить SIM разъем на microSIM				-> 5039600696
+ 3. Подобрать PCB антенну для MAIN_ANT вместо SMA разъема	-> Molex_146200-0011
+ 4. Рассмотреть возможность внешного питания от 9В		-> Питание усилителя 6..7 В
+ 5. Изменить ширину платы как внутренний размер корпуса	-> 176мм
+ 6. Заменить разъем AUX_ANT с SMA на UFL
+ 7. Предусмотреть аппаратный RESET SIM7600H			-> Замыканием двух TP 
8. Подобрать I2C LCD
+ 9. Сделать отступ по краям платы 3мм

--- Версия 1.1 ---

+ 10. Увеличить диаметр отверстий под крепление радиатора	-> 2.3мм и в BOM добавлен винт PF2-6
+ 11. Изменить расположение переходных GND отверстий под радиатором
+ 12. Скорректировать footprint VD12 (SS510)			-> SMC + SMAF
+ 13. Убрать тонкое удлинение полигона GND у R1
+ 14. Переместить линию 3V под модулем SIMCOM
+ 15. Перенести маркировку D6 (MCP130T) ближе к компоненту
+ 16. Пересмотреть маркировку диодов и D1 (SIMCOM)
+ 17. Переделать неправильную распиновку кнопок S1..S3
+ 18. Подписать на разъемах питания и динамика +
+ 19. Пересмотреть схему power-on SIMCOM (перемычки R32)	-> S5 
+ 21. BACK_ON (GPIO3) не доступно в системе			-> сигнал на ADC2
    Заменить номиналы резисторов: R64 1k, R33 22k, R34 10k
+ 22. Увеличить ширину дорожки 3V8_BAK до 2мм			-> 1.2мм
+ 23. Попробовать заменить VD5 (SP0506BAATG)			-> VD5, VD18 (ESDA6V1SC5)
+ 24. Предусмотреть перемычку для соединения BAT- с GND		-> R68
+ 25. Уменьшить яркость светодиодов HL3, HL4			-> R51 = 18k, R52 = 3.9k
+ 26. Подписать разъемы X11, X13 
+ 27. Добавить в цепь подсветки LCD ключ комутирующий подствеку с 5V
+ 28. Добавить Конденсатор и Дроссель от ЭМ помех на питание LCD
+ 29. Заменить D3 (TXS0104EPW), на поддерживающий OPEN-DRAIN I2C -> преобразователь на BSS138
+ 30. Заменить D6 на MCP130T-450, на вход 1 подать 5В

+ 31. Сгладить линию MOUT
+ 32. Добавить делитель или ограничитель между MOUT и C31		-> R69 = 3.3k, R70 = 7.5k
+ 33. Добавить эл. конденсатор по выходу DA1 (TDA2003V)		-> C38
+ 34. Скорректировать номинал R41 ( R41 = (Gv - 1) * R42 )	-> R41 = 43 Ом, Gv = 21
+ 35. Добавить умножитель 12 МГц для PCM_CLK (MCLK)		-> TXB0102DCU + NB3N501 (ICS512M) 	
+ 35. Добавить термопасту в BOM					-> GD900 3g
+ 36. Заменить DA4 на step-up (5V ~> Vamp)			-> LM2577S-ADJ
+ 37. Добавить heatsink footprint для DA2, DA4
+ 38. Добавить "карту" перемычек платы				-> jumpers_map.xls

--------------------------------------------------------------------------------------------------------

1. Добавить керамический конденсатор 50 В 0.1мкФ на выход 
   DA4 (LM2577S-ADJ) 
2. Поменять номинал R54 для уменьшения Imax_bat = 580mA (2кОм)
3. Добавить токоограничивающий резистор подсветки LCD (10 Ом, 0.5 Вт: 1210) в цепь LCD_A
4. Супрессор VD13 подобрать аналог 5KP26A на Vclamp (напряжение на выходе) на 40 В макс согласно DA2:Vin_max = 40 В 
   при этом Vbreak ~= 28..30 В, Ipeak > 100 A 
   Минимальное пробивное напряжение: 28.5 В
   Максимальное напряжение фиксации: 38..41 В
   Максимальный импульсный ток: (определяется резистором R53)
   (входной резистор R53 = 2 Ом ограничивает ток при 180 В до 90 А)
5. Диод VD12 выбрать либо на 200 В, либо поставить после VD13
6. Добавить в цепи питания резистор 0.01 Ом, 1 Вт для измерения тока 
7. Заменить С58 на емкость побольше (1000 мкФ)
8. Поставить помощнее R37, R41, R42, R43
9. Выделить отдельную цепь питания Vin -> 12 В для аудиоусилителя  (LM2596S-ADJ \ LM2596R-ADJ)
10.Разработать схему корректного автоматического включения модуля (замена кнопки S5)

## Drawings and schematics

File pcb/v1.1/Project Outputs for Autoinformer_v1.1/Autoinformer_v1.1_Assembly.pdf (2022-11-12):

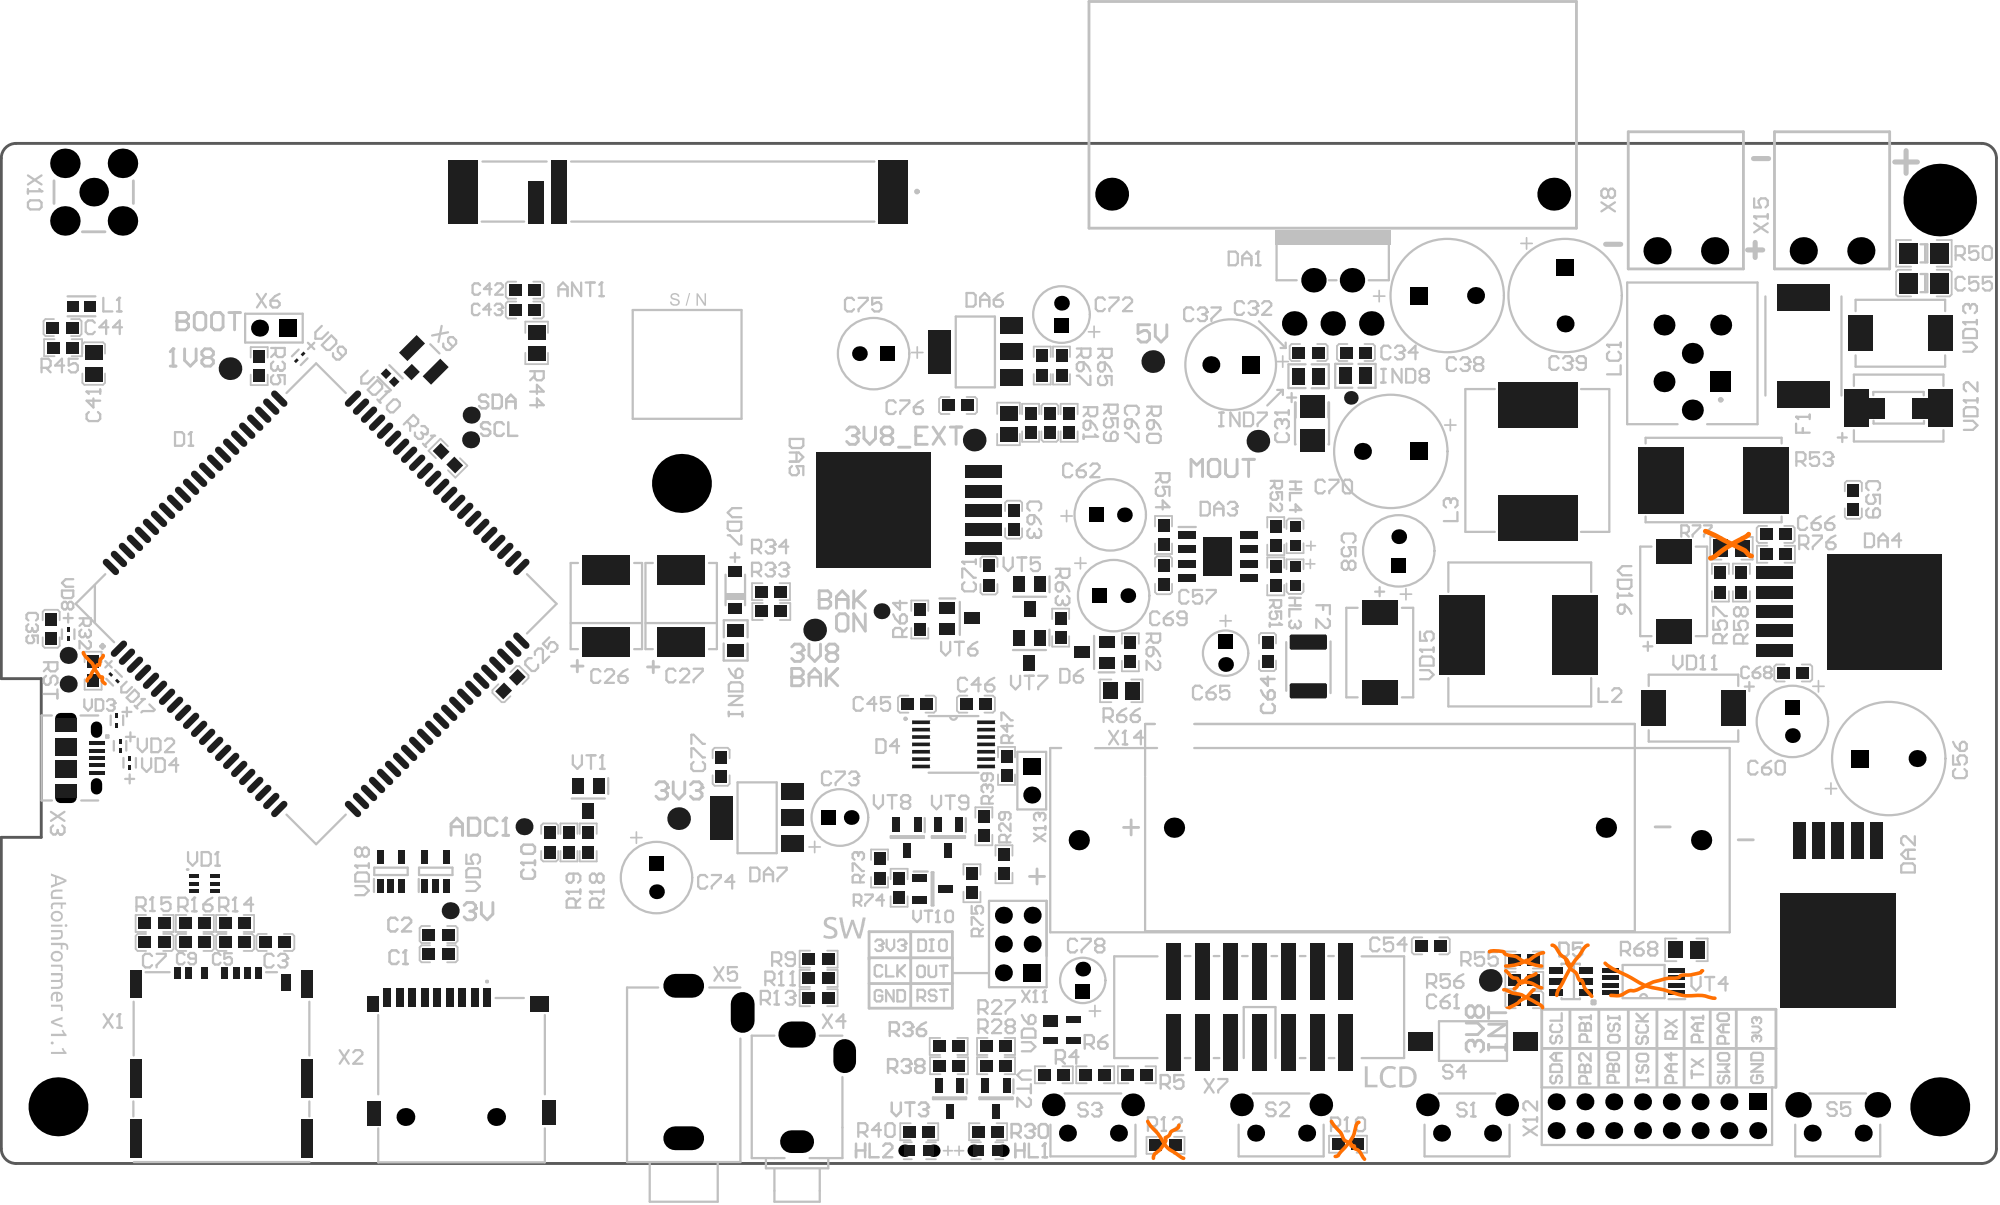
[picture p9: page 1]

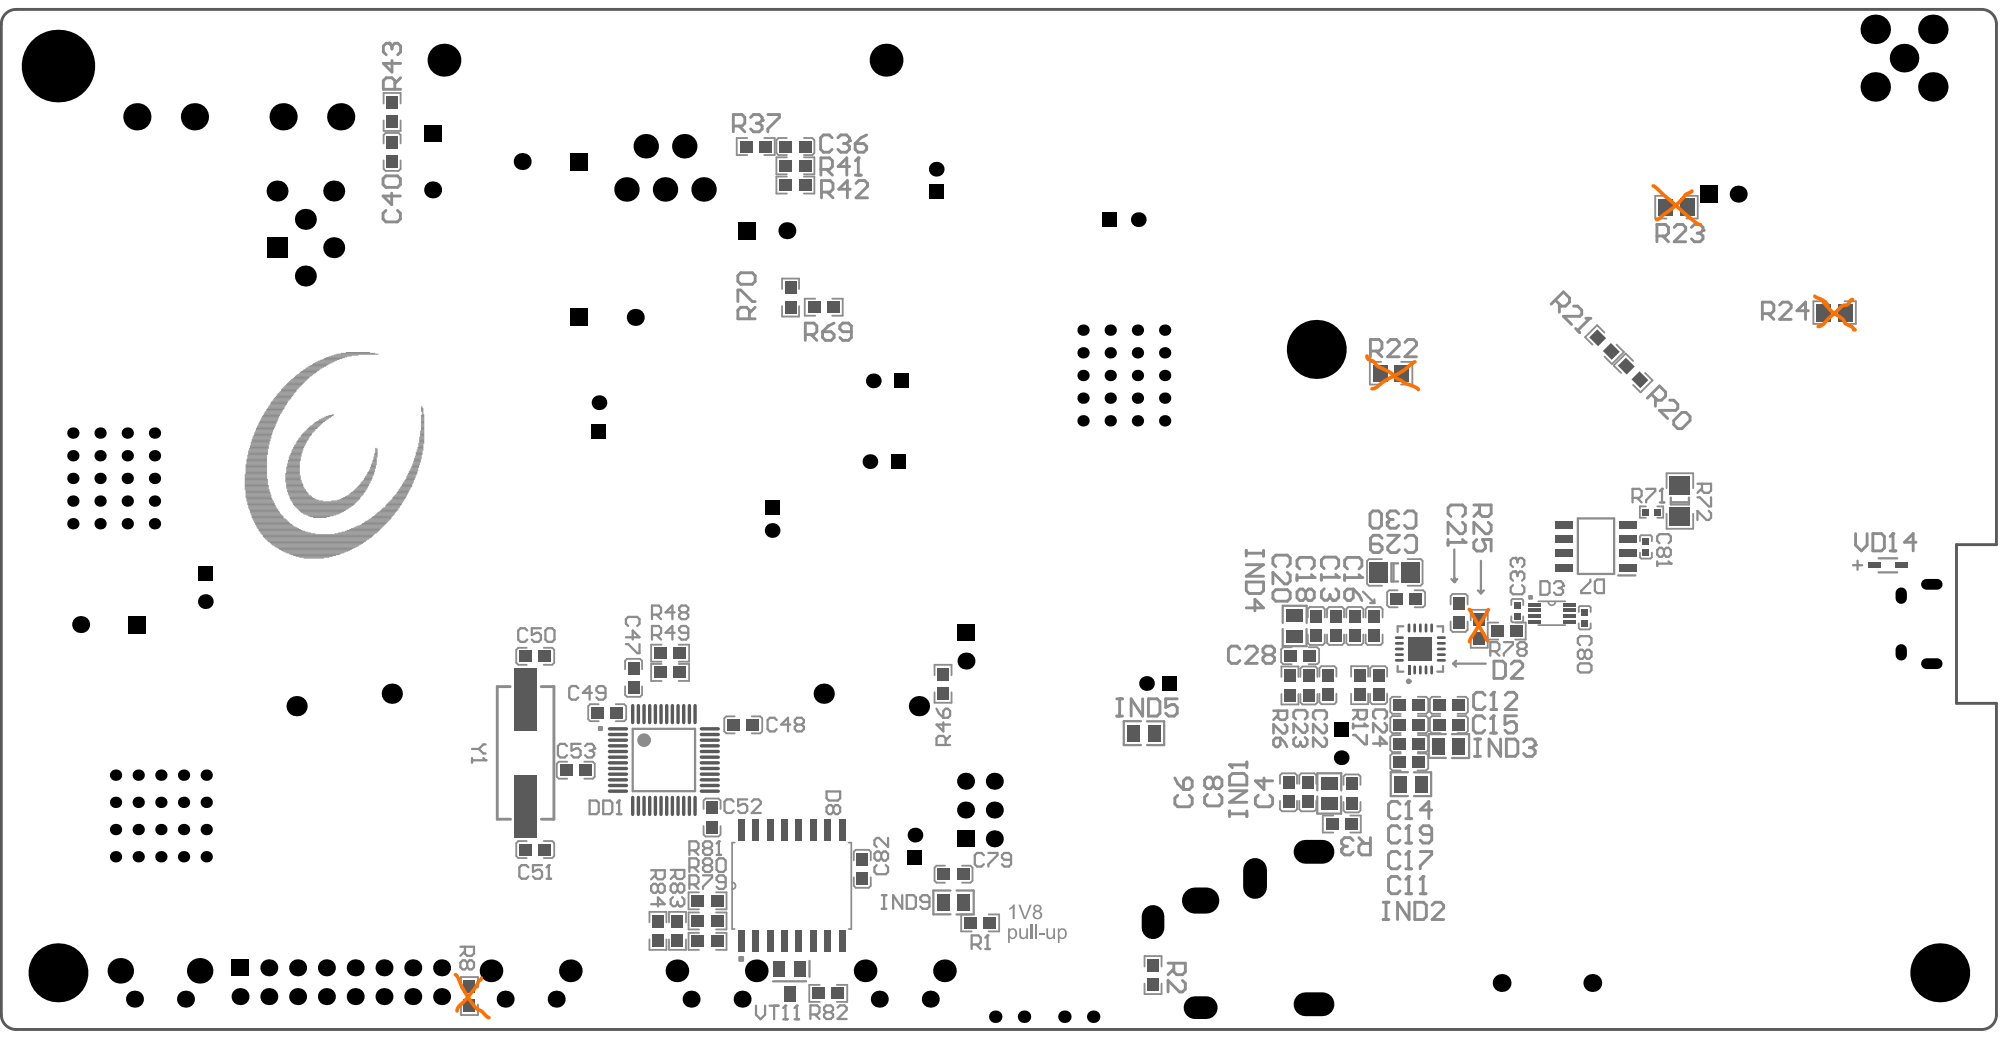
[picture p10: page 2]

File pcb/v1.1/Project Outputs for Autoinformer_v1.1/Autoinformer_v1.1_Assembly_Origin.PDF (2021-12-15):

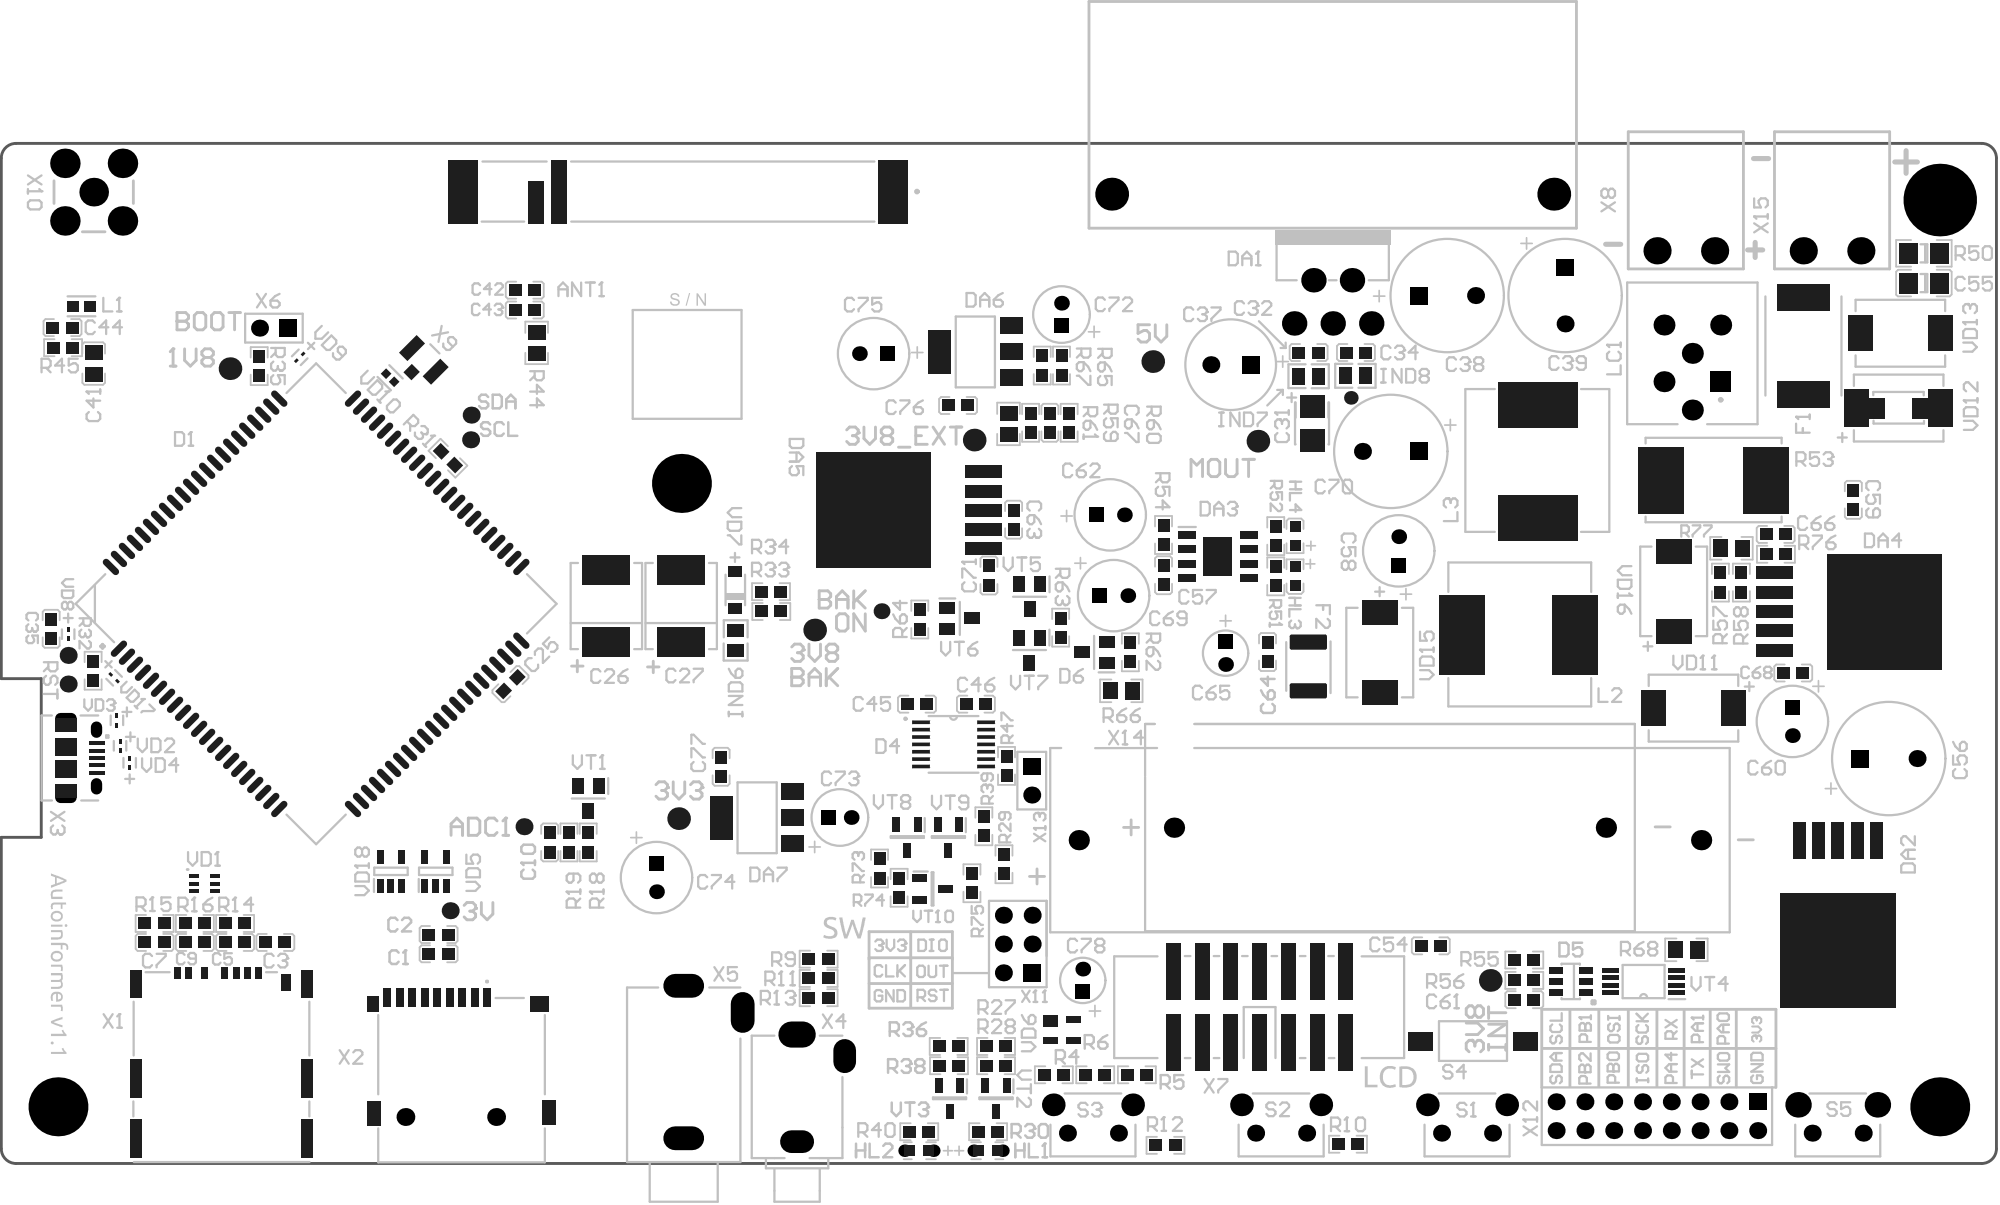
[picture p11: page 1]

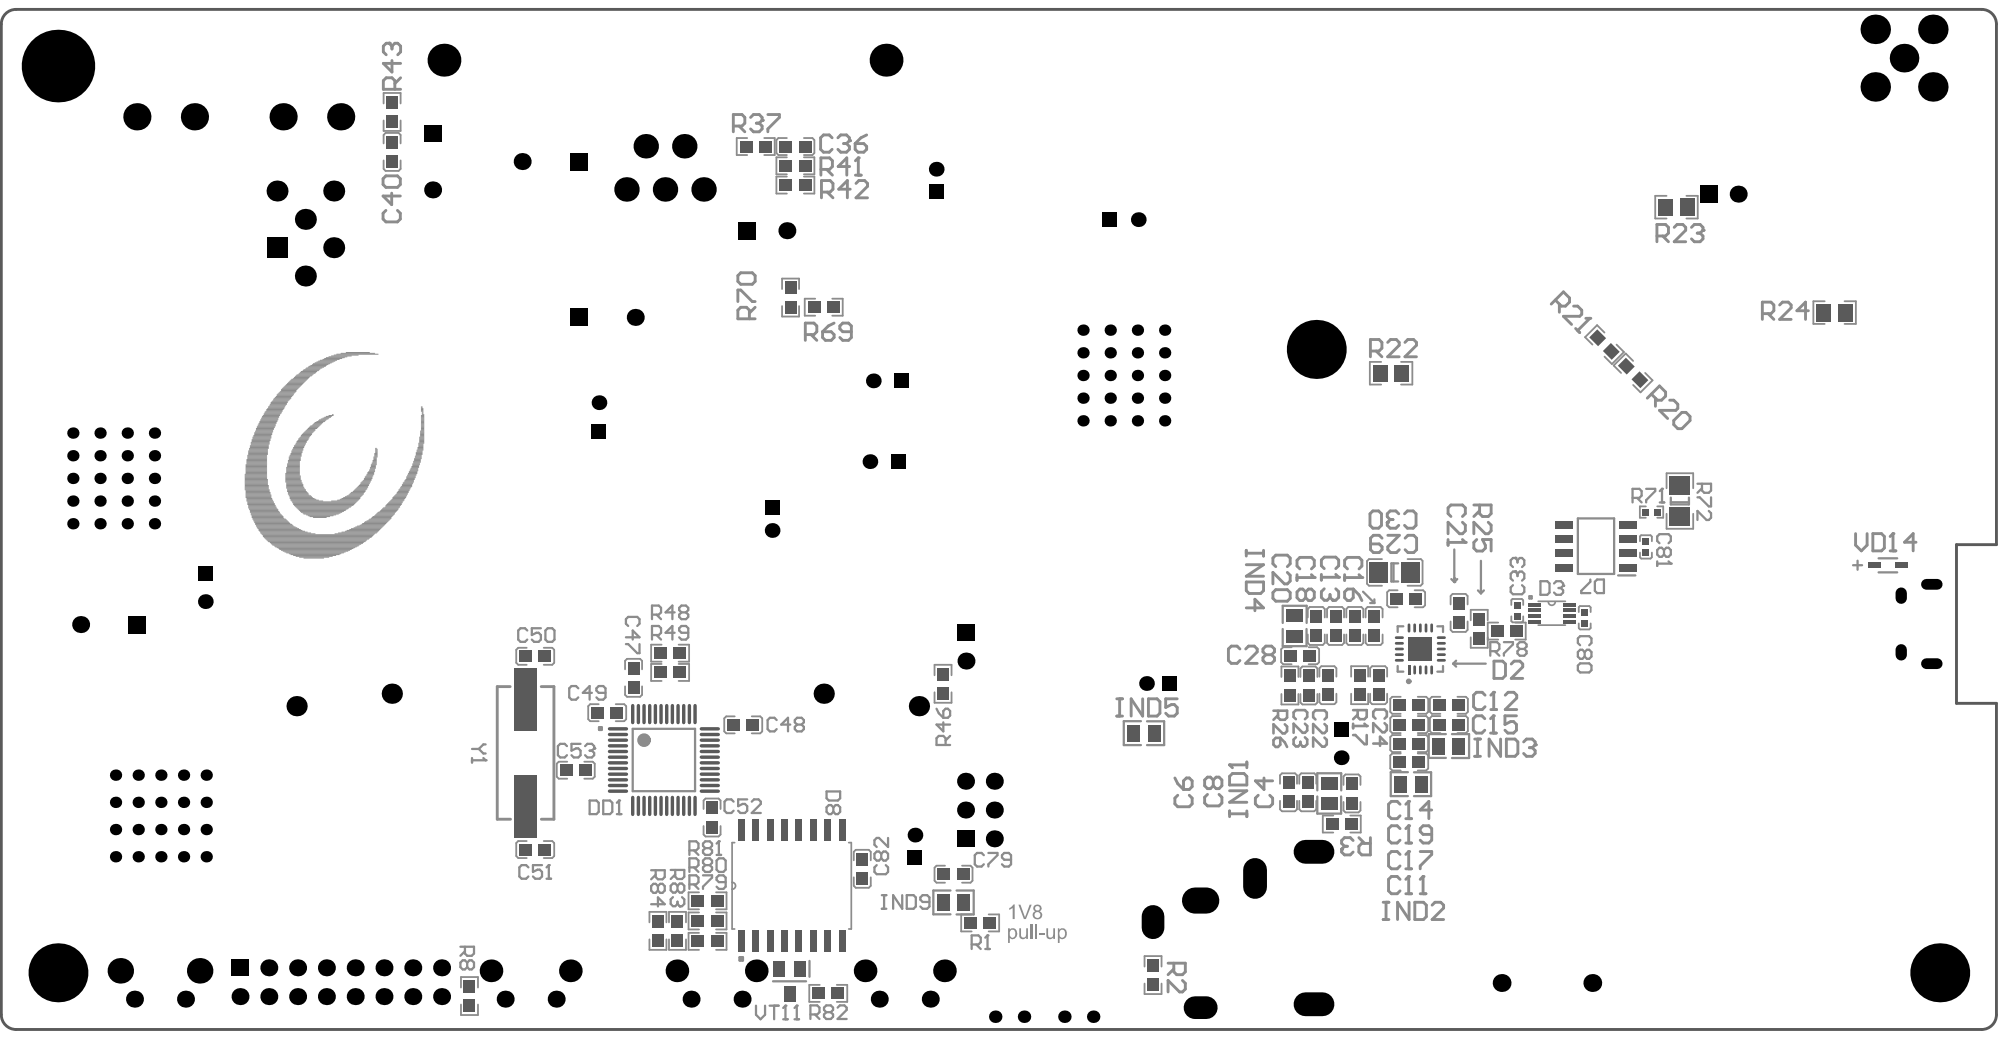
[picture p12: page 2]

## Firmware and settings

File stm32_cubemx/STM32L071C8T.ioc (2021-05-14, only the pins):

Mcu.UserName=STM32L071C8Tx
PA0.Signal=GPIO_Output
PA1.Signal=GPIO_Output
PA10.Signal=USART1_RX
PA13.Signal=SYS_SWDIO
PA14.Signal=SYS_SWCLK
PA2.Signal=LPUART1_TX
PA3.Signal=LPUART1_RX
PA4.Signal=GPIO_Output
PA5.Signal=SPI1_SCK
PA6.Signal=SPI1_MISO
PA7.Signal=SPI1_MOSI
PA9.Signal=USART1_TX
PB10.Signal=I2C2_SCL
PB11.Signal=I2C2_SDA
PB3.Signal=GPIO_Output
PB6.Signal=I2C1_SCL
PB7.Signal=I2C1_SDA
PH0-OSC_IN.Signal=RCC_OSC_IN
PH1-OSC_OUT.Signal=RCC_OSC_OUT

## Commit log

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2021-03-16 pcb lib updated, connectors added
    [Sheet1.SchDoc, orders.xlsx]
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2021-03-24 audio iface started, power updated
    [Autoinformer.PrjPcb, Sheet1.SchDoc]
2021-03-25 audio added, reserve power started
    [Autoinformer.PrjPcb, Sheet1.SchDoc]
2021-03-26 antennas and reserve power added
    [Autoinformer.PrjPcb, Sheet1.SchDoc]
2021-03-29 sheet2 added, 5V power net updated
    [Autoinformer.PrjPcb, Sheet1.SchDoc, Sheet2.SchDoc]
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2021-03-31 internal accum power started
    [Sheet1.SchDoc]
2021-04-01 batt charger + protector started
    [Sheet1.SchDoc, Sheet2.SchDoc]
2021-04-05 battery charger scheme added
    [Autoinformer.PrjPcb, Sheet1.SchDoc, Sheet2.SchDoc]
2021-04-06 scheme lists updated, controls added
    [Autoinformer.PrjPcb, Sh1_MPU.SchDoc, Sh2_MCU.SchDoc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]
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2021-04-09 pcb workaround
    [Sh1_MPU.SchDoc, Sh3_Power.SchDoc]
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2021-04-14 pcb: new board sizes - 110x160 mm
    [Sh1_MPU.SchDoc]
2021-04-16 pcb updated: antennas, audio AGND poly, mcu added
    [Autoinformer.PrjPcb, Sh1_MPU.SchDoc, Sh2_MCU.SchDoc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]
2021-04-19 pcb: lcb and mcu updated
    [Sh1_MPU.SchDoc, Sh2_MCU.SchDoc, Sh3_Power.SchDoc]
2021-04-20 lcd connector changed, mounting holes and polys added
    [Sh1_MPU.SchDoc]
2021-04-23 v.1 110x160 prepolygon version
    [Autoinformer.PrjPcb, Sh1_MPU.SchDoc]
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2021-04-27 power updated, SMA replacement started
    [Autoinformer.PrjPcb, Sh1_MPU.SchDoc]
2021-04-28 pcb: antennas placement updated
    [Autoinformer.PrjPcb, Sh1_MPU.SchDoc, Sh3_Power.SchDoc]
2021-04-28 pcb: power placement workaround
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2021-04-30 audio part AGND update
    [Sh1_MPU.SchDoc]
2021-05-11 pcb: audio workaround
    [Sh1_MPU.SchDoc]
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2021-05-13 pcb: level-shifters fix, mcu started
    [Autoinformer.PrjPcb, Sh1_MPU.SchDoc, Sh2_MCU.SchDoc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]
2021-05-14 pcb: mcu part updated
    [Autoinformer.PrjPcb, Sh1_MPU.SchDoc, Sh2_MCU.SchDoc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]
2021-05-17 radiator added, new pcb length 100 mm
    [Autoinformer.PrjPcb, HS117-30.ipt, Sh1_MPU.SchDoc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]
2021-05-18 antennas updated, snake routes added
    [Autoinformer.PrjPcb, Sh1_MPU.SchDoc]
2021-05-19 audio info and fix added, usb + antennas routing updated
    [Autoinformer.PrjPcb, Sh1_MPU.SchDoc, Sh2_MCU.SchDoc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]
2021-05-20 audio connectors placement set, 3d added
    [Autoinformer.PrjPcb, Sh1_MPU.SchDoc]
2021-05-20 audio connectors 3d parts added
    [PY-401N.ipt, PY-601N.ipt]
2021-05-21 audio connectors updated, LED added
    [Autoinformer.PrjPcb, PY-401N.ipt, PY-601N.ipt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]
2021-05-24 MICBIAS resistor fix
    [Autoinformer.PrjPcb, Sh1_MPU.SchDoc]
2021-05-25 micbias adc net added, voltage fix needed
    [Autoinformer.PrjPcb, Sh1_MPU.SchDoc, Sh2_MCU.SchDoc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]
2021-05-26 audio input for ADC reworked
    [Sh1_MPU.SchDoc, Sh3_Power.SchDoc]
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2021-05-28 GND poly updated, antennas poly added
    [Autoinformer.PrjPcb, Sh1_MPU.SchDoc, Sh3_Power.SchDoc]
2021-05-31 DRC rules, GND poly updated
    [Autoinformer.PrjPcb, Sh1_MPU.SchDoc, Sh2_MCU.SchDoc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]
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2021-06-02 PCB Antenna workaround started
    [Autoinformer.PrjPcb, Sh1_MPU.SchDoc]
2021-06-04 pcb antenna workaround..
    [Sh1_MPU.SchDoc]
2021-06-07 new power placement workaround
    [Sh1_MPU.SchDoc, Sh3_Power.SchDoc]
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2021-06-09 pcb: mpu placement, board sizes 90x176, audio part updated
    [Autoinformer.PrjPcb]
2021-06-10 pcb: gnd poly updated, main antenna added
    [Sh1_MPU.SchDoc, Sh2_MCU.SchDoc, Sh3_Power.SchDoc]
2021-06-11 reset added, GND, Antennas polys updated
    [Autoinformer.PrjPcb, Sh1_MPU.SchDoc, Sh2_MCU.SchDoc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]
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2021-06-13 Antennas GND polys updated, debug resistors added
    [Autoinformer.PrjPcb, Sh1_MPU.SchDoc, Sh2_MCU.SchDoc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]
2021-06-16 BOM preparing started, pcb finishing workaround
    [Autoinformer.PrjPcb, Sh1_MPU.SchDoc, Sh2_MCU.SchDoc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]
2021-06-17 mounting holes rule updated, ADC transistor changed, silk updated
    [Autoinformer.PrjPcb, Sh1_MPU.SchDoc, Sh3_Power.SchDoc]
2021-06-18 rezonit gerbers added, BOM started
    [Autoinformer.PrjPcb, AutoinformerBOM.xls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]
2021-06-19 components parameters updated, BOM updated, Gerbers rebuild needed
    [Autoinformer.PrjPcb, AutoinformerBOM.xls, Sh1_MPU.SchDoc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]
2021-06-21 TP renamed, minor pcb changes
    [Autoinformer.PrjPcb, AutoinformerBOM.xls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]
2021-06-21 BOM updated, TODO: Gerbers
    [AutoinformerBOM.xls]
2021-06-22 usb-boot config added, sd route length aligned, buttons connection option added
    [Autoinformer.PrjPcb, AutoinformerBOM.xls, Sh1_MPU.SchDoc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]
2021-06-23 fabrication preparing.. footprints updated
    [Autoinformer.PrjPcb, AutoinformerBOM.xls, Sh1_MPU.SchDoc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]
2021-06-24 gerbers updated, silk and solder mask errors fixed, vias -> tented
    [Autoinformer.PrjPcb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]
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2021-07-22 BOM , TODO updated
    [AutoinformerBOM_old.xls, Autoinformer_v1.0_BOM.xls]
2021-08-16 pcb v1.0 folder added, TODO updated
    [Autoinformer.PrjPcb, AutoinformerBOM_old.xls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]
2021-08-24 v1.1 started, TODO updated
    [Autoinformer.PrjPcb, AutoinformerBOM_old.xls, Autoinformer_v1.0_BOM.xls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]
2021-08-24 v1.0 test results added
    [Autoinformer_v1.0_Tests.xlsx]
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2021-08-27 v1.0 test results updated
    [Autoinformer_v1.0_Tests.xlsx]
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2021-09-01 v1.1 work on tasks from TODO
    [Sh1_MPU.SchDoc, Sh3_Power.SchDoc]
2021-09-14 i2c level shifters workaround, MOUT todo added
    [Autoinformer_v1.0_Tests.xlsx, Autoinformer_v1.1.PrjPcb, Sh1_MPU.SchDoc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]
2021-09-17 audio amplifier gain formula added at sh1
    [Sh1_MPU.SchDoc]
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2021-09-20 1.1 mout, i2c shifter updated
    [Autoinformer_v1.1.PrjPcb, Sh1_MPU.SchDoc, Sh3_Power.SchDoc]
2021-09-21 12 MHz gen added, misc fixes
    [Sh1_MPU.SchDoc, Sh3_Power.SchDoc]
2021-09-22 DC-DC step-up added for TDA2003 power
    [Autoinformer_v1.1.PrjPcb, Sh1_MPU.SchDoc, Sh3_Power.SchDoc]
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2021-09-27 clock pcm to 12 MHz workaround
    [Autoinformer_v1.1.PrjPcb, Sh1_MPU.SchDoc, Sh3_Power.SchDoc]
2021-09-28 PCM_CLK multiplier added, SD TVS changed
    [Autoinformer_v1.1.PrjPcb, Sh1_MPU.SchDoc]
2021-09-29 jumpers map added, misc pcb updates
    [Autoinformer_v1.0_BOM.xls, Sh1_MPU.SchDoc, Sh3_Power.SchDoc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]
2021-10-04 v1.1 gerbers and BOM added
    [Autoinformer_v1.1.PrjPcb, Autoinformer_v1.1_BOM.xls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]
2021-10-06 v1.1 BOM and Gerbers updated
    [Autoinformer_v1.1_BOM.xls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]
2021-10-07 misc pcb fixes. gerbers need update
    [Autoinformer_v1.1.PrjPcb]
2021-10-08 SN added, logo moved to bot
    [Autoinformer_v1.1.PrjPcb, Sh3_Power.SchDoc]
2021-10-15 PCF8574 for LCD adding workaround
    [Sh1_MPU.SchDoc]
2021-10-18 lcd i2c pcf8574 adding started
    [Sh1_MPU.SchDoc, Sh2_MCU.SchDoc]
2021-10-19 LCD connector workaround
    [Sh1_MPU.SchDoc, Sh2_MCU.SchDoc, Sh3_Power.SchDoc]
2021-10-20 new lcd connector added
    [Autoinformer_v1.1.PrjPcb, Sh1_MPU.SchDoc, Sh2_MCU.SchDoc]
2021-10-21 v1.1 Gerbers and BOM updated
    [Autoinformer_v1.1.PrjPcb, Autoinformer_v1.1_BOM.xls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]
2021-10-25 v1.1 BOM links updated
    [Autoinformer_v1.1.PrjPcb, Autoinformer_v1.1_BOM.xls, Sh1_MPU.SchDoc]
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2023-10-07 submodule updated, readme reworked
    [AutoInformer_components.xlsx, Autoinformer v1.1 BOM_КП_Онелек_3.xls, Sheet1.SchDoc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]
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
